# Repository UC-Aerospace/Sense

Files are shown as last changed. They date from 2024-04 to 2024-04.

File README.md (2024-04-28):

# MicroSense '24

MicroSense is a sensor package for the UCA Electrical Tutorials for 2024. It is a 18.24x10mm 2 layer PCB with the following sensors: 
 
1) LSM6DS3TR-C 6-axis IMU
2) LPS22HB Barometer
3) LIS2MDL 3-axis Magnetometer
 
Additionally there is also space for a H3LIS100DLTR High-g accelerometer as a future provision. 
All communication is over I2C and powered by 3.3V.
 
## Pinout

1 - SCL  
2 - IMU_INT_1  
3 - SDA  
4 - 3V3  
5 - X  
6 - GND  

## Photos





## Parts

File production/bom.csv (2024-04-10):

Designator | Footprint | Quantity | Value | LCSC Part #
C1, C2, C3, C6 | 0402 | 4 | 100n
C4 | 0402 | 1 | 220n
C5 | 0402 | 1 | 10u
J1 | PinSocket_1x03_P2.54mm_Vertical | 1 | Callistated 1
J2 | PinSocket_1x03_P2.54mm_Vertical | 1 | Callistated 2
U1 | LGA-14_3x2.5mm_P0.5mm_LayoutBorder3x4y | 1 | LSM6DS3TR-C | C967633
U2 | ST_HLGA-10_2x2mm_P0.5mm_LayoutBorder3x2y | 1 | LPS22HB | C94049
U3 | LGA-12_2x2mm_P0.5mm | 1 | LIS2MDL | C919695
U4 | LGA-16_3x3mm_P0.5mm_LayoutBorder3x5y | 1 | H3LIS100DLTR | C2655068

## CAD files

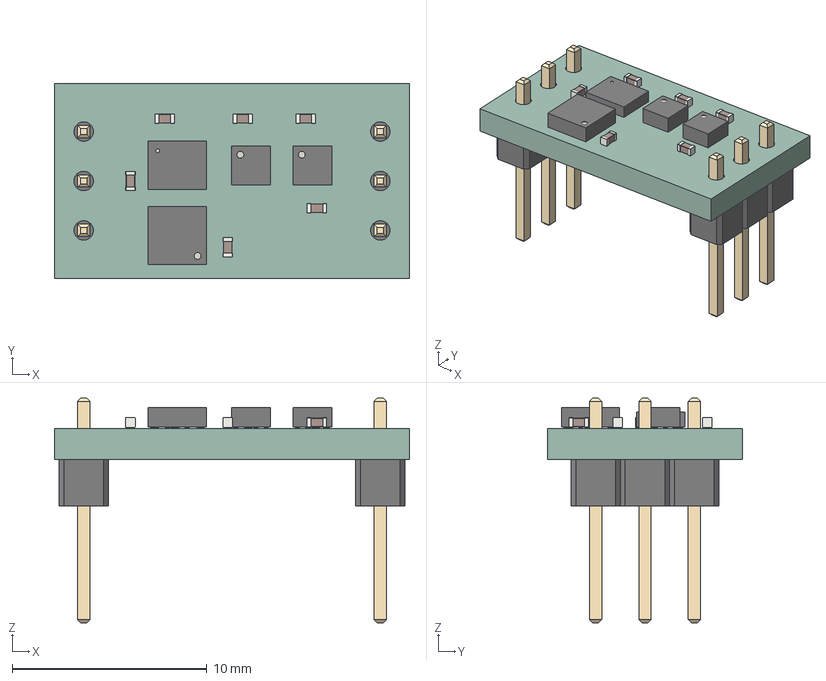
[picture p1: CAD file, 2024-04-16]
Sense.step
18.2 x 10.0 x 11.5 mm
C_0402_1005Metric x 6
PinHeader_1x03_P254mm_Vertical x 2
LGA_16_3x3mm_P05mm_LayoutBorder3x5y
LGA_14_3x25mm_P05mm_LayoutBorder3x4y
LGA_12_2x2mm_P05mm x 2
Sense_PCB

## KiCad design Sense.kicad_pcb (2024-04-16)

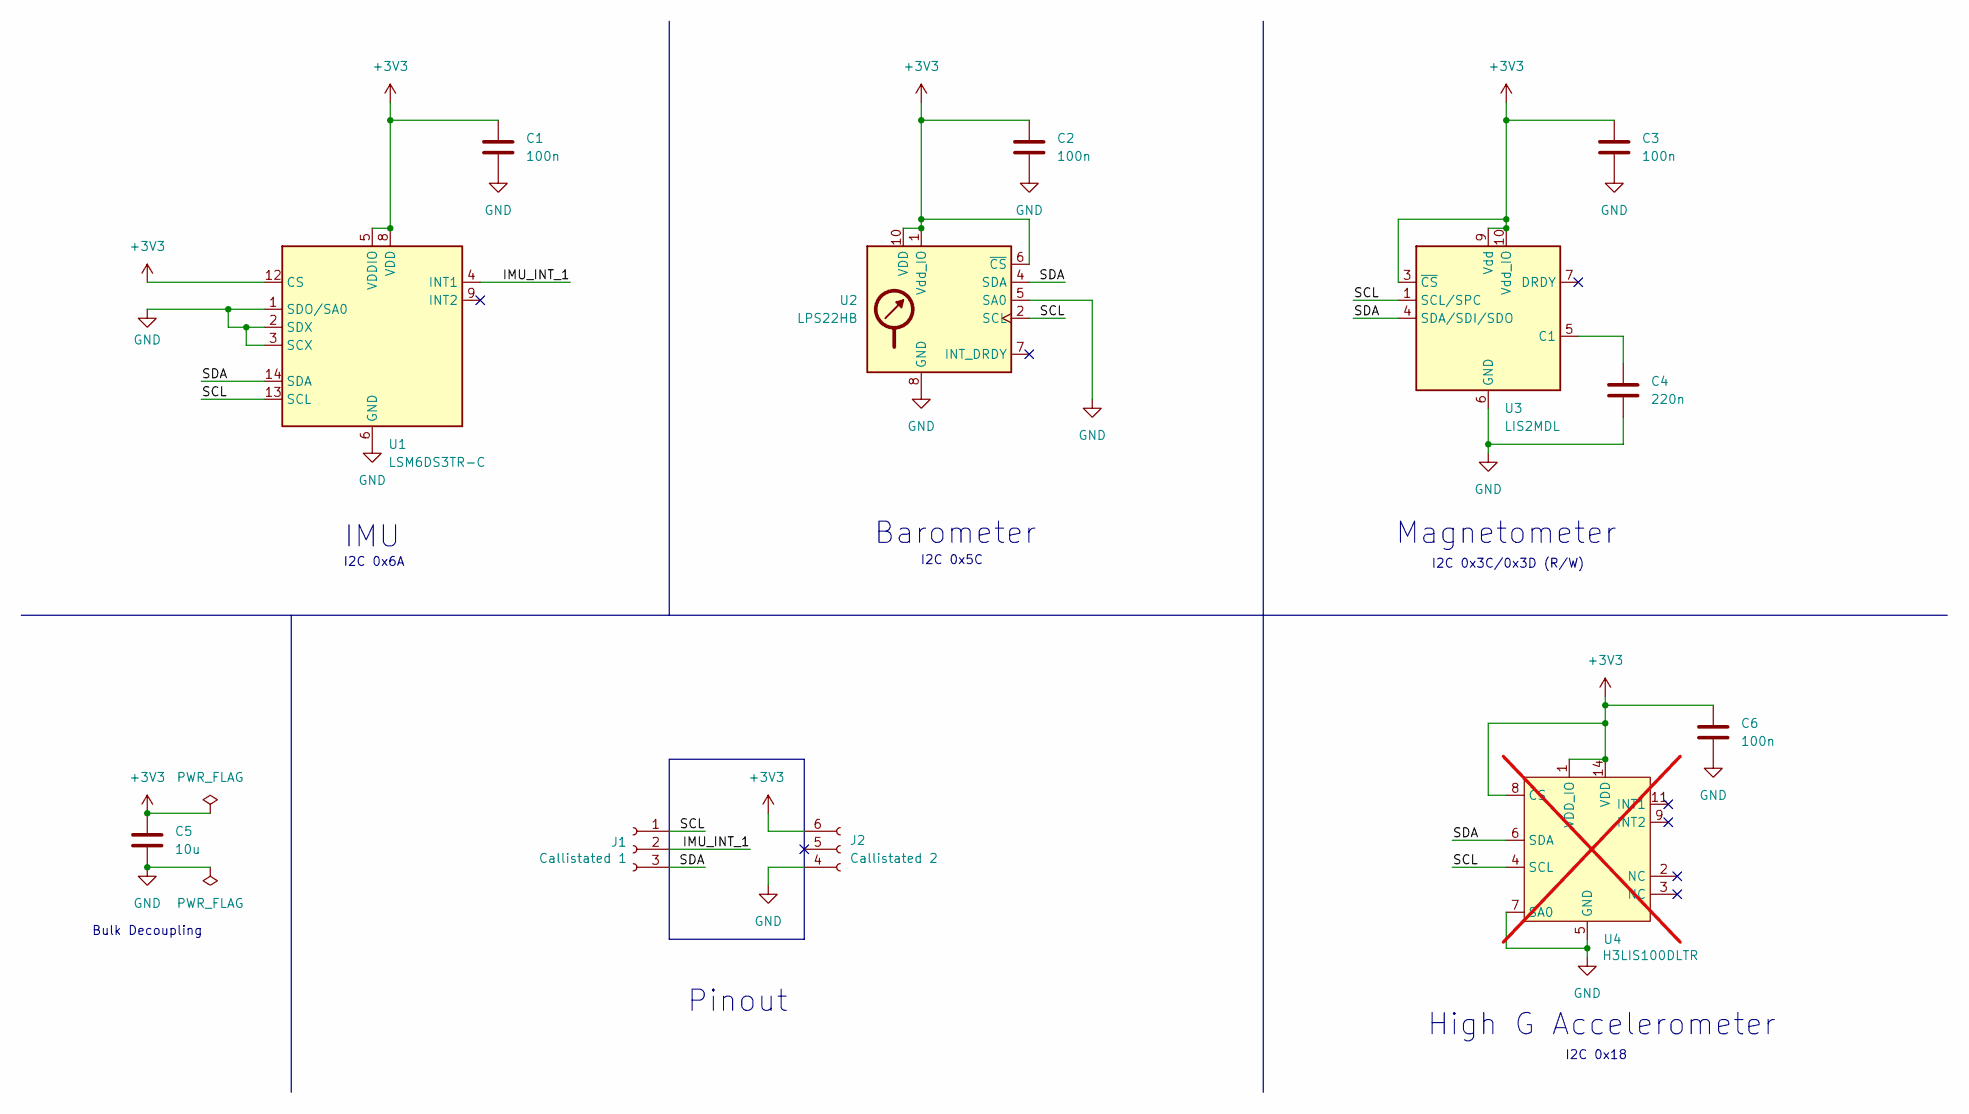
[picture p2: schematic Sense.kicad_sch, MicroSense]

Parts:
C1, C2, C3, C6: 100n; C_0402_1005Metric
C4: 220n; C_0402_1005Metric
C5: 10u; C_0402_1005Metric
J1: Callistated 1; PinSocket_1x03_P2.54mm_Vertical
J2: Callistated 2; PinSocket_1x03_P2.54mm_Vertical
U1: LSM6DS3TR-C; LGA-14_3x2.5mm_P0.5mm_LayoutBorder3x4y; MPN C967633
U2: LPS22HB; ST_HLGA-10_2x2mm_P0.5mm_LayoutBorder3x2y; MPN C94049
U3: LIS2MDL; LGA-12_2x2mm_P0.5mm; MPN C919695
U4: H3LIS100DLTR; LGA-16_3x3mm_P0.5mm_LayoutBorder3x5y; MPN C2655068; not fitted

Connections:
+3V3: C1.1, C2.1, C3.1, C5.1, C6.1, J2.6 (Pin_1), U1.5 (VDDIO), U1.8 (VDD), U1.12 (CS), U2.1 (Vdd_IO), U2.6 (~CS), U2.10 (VDD), U3.3 (~CS), U3.9 (Vdd), U3.10 (Vdd_IO), U4.1 (VDD_IO), U4.8 (CS), U4.14 (VDD), U4.15 (RES_VDD)
/IMU_INT_1: J1.2, U1.4 (INT1)
/SCL: J1.1, U1.13 (SCL), U2.2 (SCL), U3.1 (SCL/SPC), U4.4 (SCL)
/SDA: J1.3, U1.14 (SDA), U2.4 (SDA), U3.4 (SDA/SDI/SDO), U4.6 (SDA)
GND: C1.2, C2.2, C3.2, C4.2, C5.2, C6.2, J2.4 (Pin_3), U1.1 (SDO/SA0), U1.2 (SDX), U1.3 (SCX), U1.6 (GND), U1.7 (GND), U2.3 (GND), U2.5 (SA0), U2.8 (GND), U2.9 (GND), U3.6 (GND), U3.8 (GND), U4.5 (GND), U4.7 (SA0), U4.10 (RES_GND), U4.12 (GND), U4.13 (GND), U4.16 (GND)
unnamed: C4.1, U3.5 (C1)

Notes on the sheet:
Barometer
IMU
I2C 0x6A
Bulk Decoupling
Pinout
I2C 0x18
I2C 0x5C
High G Accelerometer
Magnetometer
I2C 0x3C/0x3D (R/W)

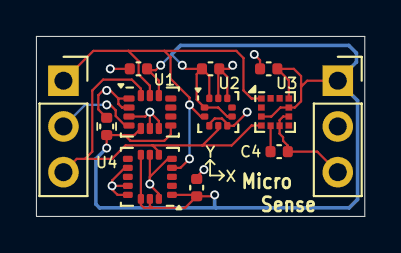
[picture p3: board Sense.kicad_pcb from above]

Board: 2 copper layers, 18.2 x 10.0 mm, 12 parts (0 on the bottom side), 6 nets.

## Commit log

2024-03-26 Initial Rough Idea
    [Sense-B_Cu.gbr, Sense-B_Mask.gbr, Sense-B_Paste.gbr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]
2024-04-06 Abandoned castellated pads, updated with LCSC parts
    [Sense-B_Cu.gbr, Sense-B_Mask.gbr, Sense-B_Paste.gbr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]
2024-04-10 Version C.0
    Added high g accelerometer option
    [Sense.kicad_pcb, Sense.kicad_sch, Sense_Pannel.kicad_pcb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]
2024-04-11 Aligned to grid and fixed pin numbering
    [Sense.kicad_pcb, Sense.kicad_sch]
2024-04-12 Added 3D model
    [Sense.step]
2024-04-16 Updated after review
    [Sense.kicad_pcb, Sense.kicad_sch, positions.csv]
2024-04-16 Fixed the couple of things that I broke, updated STEP
    [Sense.kicad_pcb, Sense.kicad_sch, Sense.step]
